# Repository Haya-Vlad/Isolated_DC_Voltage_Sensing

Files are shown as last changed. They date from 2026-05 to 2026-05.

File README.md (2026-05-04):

# Isolated DC Voltage Sensing

A fully isolated DC bus voltage sensing circuit designed for power electronics applications, capable of sensing **0–300 V DC** and scaling the signal to a **0–3.3 V ADC range** using the AMC1200 isolation amplifier.

## Table of Contents

- [Overview](#overview)
- [Features](#features)
- [Circuit Architecture](#circuit-architecture)
- [Signal Chain](#signal-chain)
- [Components](#components)
- [Repository Structure](#repository-structure)
- [Hardware Design](#hardware-design)
- [Power Supply](#power-supply)
- [Getting Started](#getting-started)
- [Bill of Materials](#bill-of-materials)
- [License](#license)

---

## Overview

This project implements a  isolated DC voltage sensing solution for high-voltage DC bus measurements (up to 300 V). The circuit uses the **AMC1200** precision isolation amplifier to safely measure high-voltage DC signals while maintaining full electrical isolation between the high-voltage side and the low-voltage (microcontroller/ADC) side.

The design is suitable for use in:
- Motor drives and inverters
- Battery management systems (BMS)
- Solar/PV converters
- DC-DC converters
- Any power electronics system requiring isolated voltage feedback

---

## Features

-  **Input range:** 0–300 V DC
-  **Output range:** 0–3.3 V (direct ADC-compatible)
-  **Full galvanic isolation** via AMC1200
-  **Anti-aliasing filter** at ADC input (150 Ω + 1 nF)
-  **RC pre-filter** for noise reduction before AMC1200
-  **Dual isolated power supply** using LD1117 and L7805 regulators
-  **Unipolar signal path** — no DC offset reference required
-  **MCP6002 op-amp** for output signal conditioning
-  **Designed in Eagle CAD**, Gerber files included
-  **Practically implemented and tested**

---

## Circuit Architecture

```
DC Bus (0–300V)
      │
      ▼
┌─────────────────────┐
│  Resistor Divider   │  620kΩ × 3 on each rail
│  (High-side input   │  which scales to ±250mV differential
│   attenuation)      │
└────────┬────────────┘
         │ Differential ±250mV
         ▼
┌─────────────────────┐
│      AMC1200        │  Isolation amplifier
│  (Isolation Stage)  │  Gain = 8 (±250mV in → ±2V out)
│                     │  Galvanic isolation barrier
└────────┬────────────┘
         │
         ▼
┌─────────────────────┐
│   RC Filter Stage   │  Initial noise suppression
│  (12Ω + 330pF)      │
└────────┬────────────┘
         │
         ▼
┌─────────────────────┐
│      MCP6002        │  Signal conditioning op-amp
│  (Output Scaling)   │  Scales to 0–3.3V ADC range
│                     │  10kΩ feedback network
└────────┬────────────┘
         │
         ▼
┌─────────────────────┐
│  Anti-Aliasing      │  150Ω + 1nF
│  Filter             │  High-frequency noise rejection
└────────┬────────────┘
         │
         ▼
    OUTPUT_TO_ADC (0–3.3V)
```

---

## Signal Chain

1. **Input Attenuation:** The DC bus voltage (0–300 V) is divided by a high-value resistor network  to produce a small differential voltage within the AMC1200's ±250 mV input range.

2. **Isolation (AMC1200):** The AMC1200 isolation amplifier provides galvanic isolation with a fixed gain of 8. The ±250 mV differential input is amplified and transferred across the isolation barrier.

3. **RC Pre-filter:** A 12 Ω + 330 pF RC filter stage provides initial high-frequency noise attenuation immediately after the AMC1200 output.

4. **Signal Conditioning (MCP6002):** The MCP6002 op-amp is configured as a scaling amplifier with a 10 kΩ feedback network. Since the DC bus signal is inherently unipolar, no DC offset reference is required so the signal maps directly into the 0–3.3 V ADC range.

5. **Anti-Aliasing Filter:** A 150 Ω + 1 nF RC filter at the ADC input provides additional high-frequency noise suppression and prevents aliasing during ADC sampling.

---

## Components

| Reference | Component | Value/Part | Description |
|---|---|---|---|
| U32 | AMC1200 | AMC1200 | Precision isolation amplifier |
| U37 | MCP6002 | MCP6002 | Dual rail-to-rail op-amp |
| CR2 | LD1117 | LD1117 | LDO voltage regulator (isolated side) |
| CR5 | L7805 | L7805 | 5V linear regulator |
| D3, D4 | HSMG-C170 | HSMG-C170 | Green & Red status LED |
| R177–R179, R183–R187 | Resistor | 620 kΩ | Input voltage divider |
| R170, R172–R173 | Resistor | 12 Ω | RC filter resistors |
| R174–R175 | Resistor | 10 kΩ | Op-amp feedback network |
| R259 | Resistor | 150 Ω | Anti-aliasing filter |
| R257, R258 | Resistor | 510 Ω | LED current limiting |
| C122, C125 | Capacitor | 330 pF | RC filter capacitors |
| C126, C127 | Capacitor | 0.1 µF | Decoupling capacitors |
| C153, C155 | Capacitor | 470 µF | Bulk filtering |
| C157, C161–C162 | Capacitor | 100 nF | Supply decoupling |
| C158 | Capacitor | 1 nF | Anti-aliasing filter capacitor |
| L3 | Ferrite Beads | 32mohms | Power supply filter |

---

## Repository Structure

```
isolated-dc-voltage-sensing/
│
├── README.md                  ← You are here
├── LICENSE
├── CHANGELOG.md
│
├── hardware/
│   ├── eagle/
│   │   ├── schematic/         ← .sch Eagle schematic files
│   │   ├── board/             ← .brd Eagle board layout files
│   │   └── libraries/         ← Custom Eagle component libraries (.lbr)
│   ├── gerber/                ← Fabrication-ready Gerber files
│   │   ├── *.GTL              (Top copper)
│   │   ├── *.GBL              (Bottom copper)
│   │   ├── *.GTS              (Top soldermask)
│   │   ├── *.GBS              (Bottom soldermask)
│   │   ├── *.GTO              (Top silkscreen)
│   │   ├── *.DRL              (Drill file)
│   │   └── gerber_readme.md
│   │
│── docs/
    ├── design_notes.md        ← Design decisions and calculations
    ├── signal_chain.md        ← Detailed signal chain analysis
    └── datasheets/            ← Key component datasheets (PDFs)
        ├── AMC1200.pdf
        ├── MCP6002.pdf
        ├── LD1117.pdf
        └── L7805.pdf
```

---

## Hardware Design

The design was created in **Autodesk Eagle CAD**. All source files are located under `hardware/eagle/`.

- **Schematic:** `hardware/eagle/schematic/`
- **Board layout:** `hardware/eagle/board/`
- **Gerber files** (ready for PCB fabrication): `hardware/gerber/`

### Power Supply Architecture

The circuit uses a **dual isolated power supply**:
- **VCC_A / GND_A** — High-voltage (DC bus) side supply, regulated via LD1117
- **VCC_B / GND_B** — Low-voltage (MCU/ADC) side supply, regulated via L7805
- **VCC_12V_A+ / VCC_12V_B+** — 12V rails feeding each regulator

The dual-supply architecture ensures that the isolation barrier of the AMC1200 is maintained across both the signal path and the power supply.

---

## Getting Started

### PCB Fabrication
1. Download the Gerber files from `hardware/gerber/`
2. Upload to your preferred PCB manufacturer (JLCPCB, PCBWay, OSHPark, etc.)
3. Recommended specs: 2-layer, 1.6 mm FR4, HASL or ENIG finish

### Assembly
1. Refer to `hardware/bom/bom.csv` for component sourcing
2. Follow the schematic in `hardware/eagle/schematic/`
3. Pay attention to orientation of AMC1200 and polarized capacitors

### Testing
1. Apply a known DC voltage of 12V to DC_A / DC_B inputs
2. Measure OUTPUT_TO_ADC with a multimeter or oscilloscope
3. Verify scaling linearity against expected values 

---

## Bill of Materials

See [`hardware/BOM`](hardware/BOM/BOM.pdf) for the complete BOM.

---

## License

This project is released under the [MIT License](LICENSE).

---

## Author

**Aditya Gohil**  
Power Electronics Design  
*Designed and practically implemented — May 2026*

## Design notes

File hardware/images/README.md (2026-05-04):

# Images

Add the following images here:

- `schematic.png` — Exported schematic from Eagle (File → Export → Image)
- `pcb_top.png` — PCB top layer render
- `pcb_bottom.png` — PCB bottom layer render
- `assembled_board.jpg` — Photo of the practically implemented board

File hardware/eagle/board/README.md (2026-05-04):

# Eagle Board Files

Place your Eagle `.brd` board layout file(s) here.

- `pe_project.brd` — PCB layout

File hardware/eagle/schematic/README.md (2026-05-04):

# Eagle Schematic Files

Place your Eagle `.sch` schematic file(s) here.

- `pe_project.sch` — Main schematic

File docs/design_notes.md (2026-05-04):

# Design Notes — Isolated DC Voltage Sensing

**Author:** Aditya Gohil  
**Date:** May 2026  
**Tool:** Autodesk Eagle CAD

---

## 1. Design Goals

- Measure DC bus voltages in the range **0–300 V**
- Provide **galvanic isolation** between high-voltage and low-voltage domains
- Output a signal in the **0–3.3 V range** suitable for direct ADC sampling
- Minimize noise at the ADC input
- Keep the design compact and cost-effective

---

## 2. Component Selection

### AMC1200 — Isolation Amplifier
The AMC1200 was chosen for its:
- Fixed gain of 8 with ±250 mV differential input range
- High isolation voltage (up to 4250 V peak)
- Low offset voltage and excellent linearity
- SPI-free, analog-in/analog-out interface — no firmware dependency

### MCP6002 — Signal Conditioning Op-Amp
The MCP6002 was selected for its:
- Rail-to-rail input/output capability
- Single-supply operation (3.3V or 5V compatible)
- Low cost, widely available dual op-amp package
- Sufficient bandwidth for DC sensing applications

### LD1117 / L7805 — Voltage Regulators
- **LD1117 (ADJ):** Used on the isolated (high-voltage) side to supply the AMC1200 VDD
- **L7805:** Used on the low-voltage side to supply the MCP6002 and output circuitry

---

## 3. Input Attenuation Network

### Resistor Divider Calculation

The DC bus voltage (0–300 V) must be scaled to the AMC1200's ±250 mV differential input range.

Each leg of the differential input uses **3 × 620 kΩ resistors in series = 1.86 MΩ**.

A **2.2 kΩ** differential sense resistor is placed between the two legs.

Differential voltage across sense resistor:
```
V_diff = V_bus × (R_sense / (2 × R_series + R_sense))
V_diff = 300 × (2200 / (2 × 1,860,000 + 2200))
V_diff ≈ 300 × (2200 / 3,722,200)
V_diff ≈ 300 × 0.000591
V_diff ≈ 177 mV  (well within ±250 mV limit)
```

This gives comfortable headroom within the AMC1200 input range.

---

## 4. AMC1200 Output Scaling

The AMC1200 has a fixed gain of **8**.

Output voltage from AMC1200 for max input (±250 mV):
```
V_out_AMC = ±250 mV × 8 = ±2 V
```

Since the DC bus signal is unipolar (0–300 V), the output of the AMC1200 is also unipolar (0 to ~1.4 V at 300 V input given the actual divider ratio).

---

## 5. MCP6002 Gain Stage

The MCP6002 is configured as a non-inverting amplifier to scale the AMC1200 output to the 0–3.3 V ADC range.

Gain is set by the 10 kΩ feedback resistors.

Since the signal is unipolar, no virtual ground or DC offset reference is needed — the signal naturally maps into the positive ADC range.

---

## 6. Filtering Strategy

### Stage 1 — RC Pre-filter (after AMC1200 output)
- **R = 12 Ω, C = 330 pF**
- Cut-off frequency: `f_c = 1 / (2π × 12 × 330×10⁻¹²) ≈ 40 MHz`
- Provides initial HF noise damping

### Stage 2 — Anti-Aliasing Filter (at ADC input)
- **R = 150 Ω, C = 1 nF**
- Cut-off frequency: `f_c = 1 / (2π × 150 × 1×10⁻⁹) ≈ 1.06 MHz`
- Prevents aliasing during ADC sampling
- This is the dominant low-pass filter in the signal chain

---

## 7. Isolation Barrier Considerations

The AMC1200 provides isolation between:
- **VCC_A / GND_A** domain (connected to DC bus side)
- **VCC_B / GND_B** domain (connected to MCU/ADC side)

Both power domains are independently regulated. The 12V input rails (VCC_12V_A+ and VCC_12V_B+) must themselves come from an isolated DC-DC converter upstream, or from separate transformer-derived supplies, to maintain the full isolation chain.

---

## 8. Known Limitations

- The resistor divider introduces some power dissipation at high bus voltages (~24 mW at 300 V) — acceptable for most applications
- The AMC1200 output is referenced to the isolated GND_A; level shifting is handled by the dual-supply scheme
- Accuracy is limited by resistor tolerance of the divider network — use 1% or 0.1% resistors for best precision

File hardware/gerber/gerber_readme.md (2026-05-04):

# Gerber Files

This folder contains the PCB fabrication files exported from Eagle CAD.

## File Naming Convention (Eagle default)

| File Extension | Layer Description |
|---|---|
| `.GTL` | Top copper layer |
| `.GBL` | Bottom copper layer |
| `.GTS` | Top soldermask |
| `.GBS` | Bottom soldermask |
| `.GTO` | Top silkscreen |
| `.GBO` | Bottom silkscreen |
| `.GKO` | Board outline (keepout) |
| `.DRL` | Drill file (Excellon) |
| `.TXT` | NC drill file |

## Recommended PCB Specs

| Parameter | Value |
|---|---|
| Layers | 2 |
| Board thickness | 1.6 mm |
| Copper weight | 1 oz (35 µm) |
| Surface finish | HASL or ENIG |
| Min trace width | 6 mil |
| Min drill size | 0.3 mm |
| Solder mask | Green (both sides)|
| Silkscreen | White (top side)  |

## Ordering

Upload the contents of this folder as a `.zip` to your PCB manufacturer.  
Tested with: JLCPCB, PCBWay.

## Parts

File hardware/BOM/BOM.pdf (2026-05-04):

Sr. No | Comment | Designator | Quantity | Manufacturer URL | Supplier | Price of each component (INR) | Price of total needed component (INR)
1 | 2.2K 1206 | R177 | 2 | https://robu.in/product/frc1206f (https://robu.in/product/frc1206f2201ts-fojan-250mw-thick-film-resistors-200v-%c2%b1100ppm-%e2%84%83-%c2%b11-2-2k%cf%89-1206-chip-resistor-surface-mount-rohs) | ROBU | 0.18 | 0.36
2 | 12R 1206 | R171, R173 | 4 | https://robu.in/product/rc1206fr- (https://robu.in/product/rc1206fr-0712rl-yageo-smd-chip-resistor-12-ohm-%c2%b1-1-250-mw-1206-3216-metric-thick-film-general-purpose) | ROBU | 0.24 | 0.96
3 | 10K 1206 | R174, R175, R176 | 3 | https://robu.in/product/cr1206j1 (https://robu.in/product/cr1206j10k0p05z-ever-ohms-tech-250mw-thick-film-resistor-%c2%b1100ppm-%e2%84%83-%c2%b15-10k%cf%89-1206-chip-resistor-surface-mount-rohs) | ROBU | 0.75 | 2.25
4 | 150R 1206 | R259 | 1 | https://robu.in/product/rc1206fr- (https://robu.in/product/rc1206fr-07150rl-yageo-250mw-thick-film-resistors-200v-%c2%b1100ppm-%e2%84%83-%c2%b11-150%cf%89-1206-chip-resistor-surface-mount-rohs) | ROBU | 0.43 | 0.43
5 | 510R 1206 | R255, R257 | 2 | | ROBU | 0.24 | 0.48
6 | 0.1uf 1206 | C127, C157, C161, C162, C158 | 7 | https://robu. | ROBU | 3 | 21

https://robu.
in/product/rc1206fr- (https://robu.in/product/rc1206fr-07510rl-yageo-res-thick-film-1206-510-ohm-1-0-25w1-4w-%c2%b1100ppm-c-pad-smd-t-r)

in/product/ac1206k (https://robu.in/product/ac1206kkx7r0bb104-yageo-cap-ceramic-0-1uf-100v-x7r-10-pad-smd-1206-125c-automotive-aec-q200-t-r)
7 | SMD LED 0603 | D3, D4
2

https://robu.
in/product/everlight (https://robu.in/product/everlight-1-5mm-blue-smd-led-pack-of-10)
ROBU | 1.41 | 2.82
8 | AMC1200 | U32 | 1 | https://robu.in/product/amc131 (https://robu.in/product/amc1311bqdwvrq1-texas-instruments-soic-8-300mil-special-purpose-amplifiers-rohs) | ROBU | 252 | 252
10 | MCP6002 | U37 | 1 | https://robu. | ROBU | 41 | 41
in/product/mcp600 (https://robu.in/product/mcp6002-i-sn-microchip-tech-2-1pa-600v-ms-4-5mv-soic-8-operational-amplifier-rohs)
11 | L7805 DIP-3 | CR5 | 1 | https://robu.in/product/1-month- (https://robu.in/product/1-month-warranty-441) | ROBU | 30 | 30
12 | LD1117 | CR2 (Regulator) | 1 | | ROBU | 19 | 19
13 | 470uf DIP | C183 | 1 | https://robu.in/product/uvr1c47 (https://robu.in/product/uvr1c471mpd1td-nichicon-470uf-16v-%c2%b120-440ma120hz-plugin-aluminum-electrolytic-capacitors-leaded-rohs) | ROBU | 13 | 13
14 | 100uf 1206 | C155 | 1 | https://robu.in/product/grm31cr (https://robu.in/product/grm31cr61a107mea8l-murata-electronics-10v-100uf-x5r-%c2%b120-1206-multilayer-ceramic-capacitors-mlcc-smd-smt-rohs) | ROBU | 20 | 20
15 | 330pf 1206 | C122, C126 | 2 | https://robu. | ROBU | 2.08 | 4.16

https://robu.
in/product/1-month- (https://robu.in/product/1-month-warranty-1381)

in/product/330pf- (https://robu.in/product/330pf-1206-surface-mount-multilayer-ceramic-capacitor-pack-of-30)
16 | 2-Pin Terminal | X1-2, B1-2 | 3 | | ROBU | 11 | 33
17 | 620K Resistor | R178, R179, R180, R185, R186, R187 | 6 | https://robu.in/product/wr12x62 (https://robu.in/product/wr12x624jtl-walsin-250mw-thick-film-resistors-200v-%c2%b1100ppm-%e2%84%83-%c2%b15-620k%cf%89-1206-chip-resistor-surface-mount-rohs) | ROBU | 0.15 | 0.9
Total | | | 32 | | | 394.48 | 441.36

https://robu.
in/product/2-pin-7- (https://robu.in/product/2-pin-7-5-mm-pcb-terminal-block)

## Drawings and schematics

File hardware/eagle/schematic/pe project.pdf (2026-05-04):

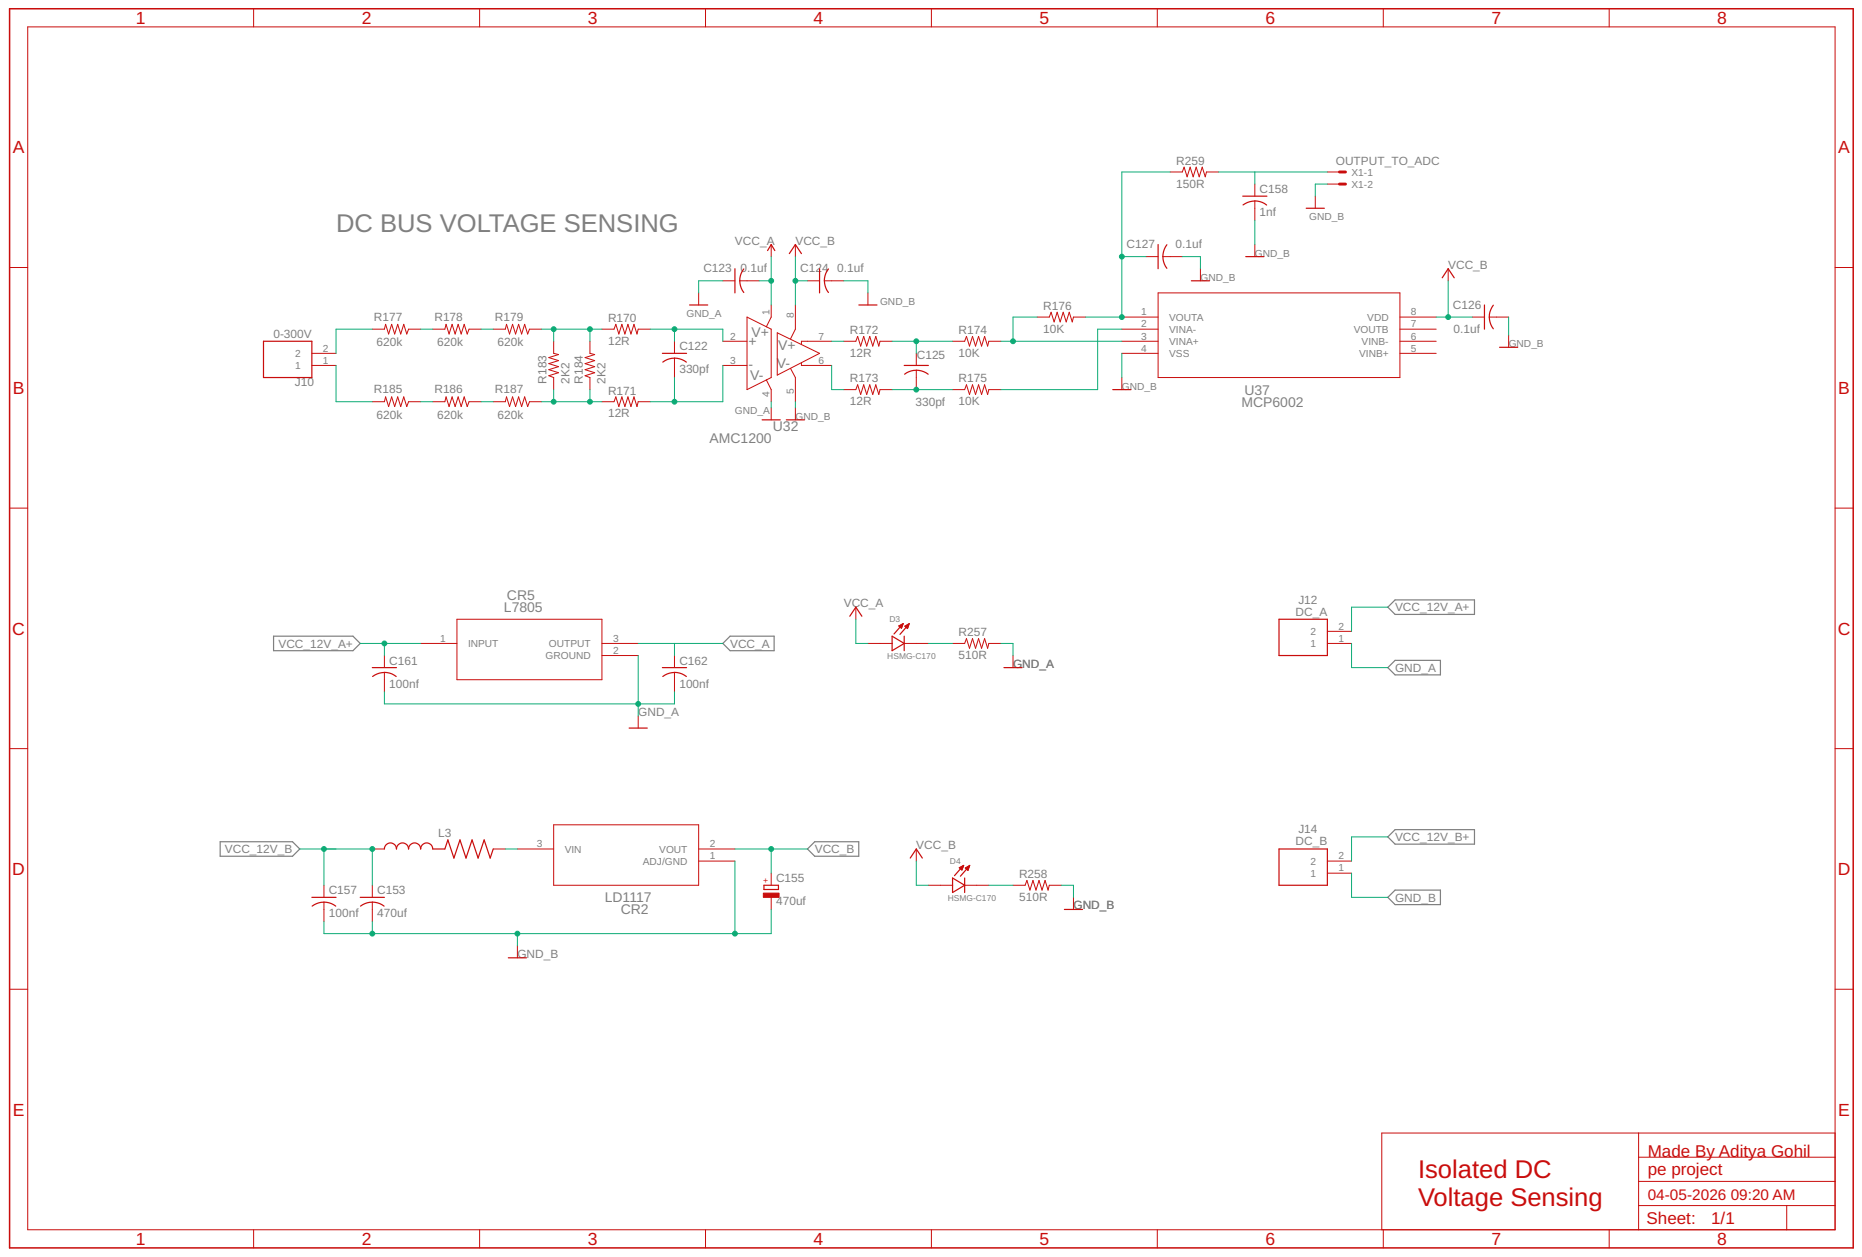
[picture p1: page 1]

DC BUS VOLTAGE SENSING

Made By Aditya Gohil
pe project

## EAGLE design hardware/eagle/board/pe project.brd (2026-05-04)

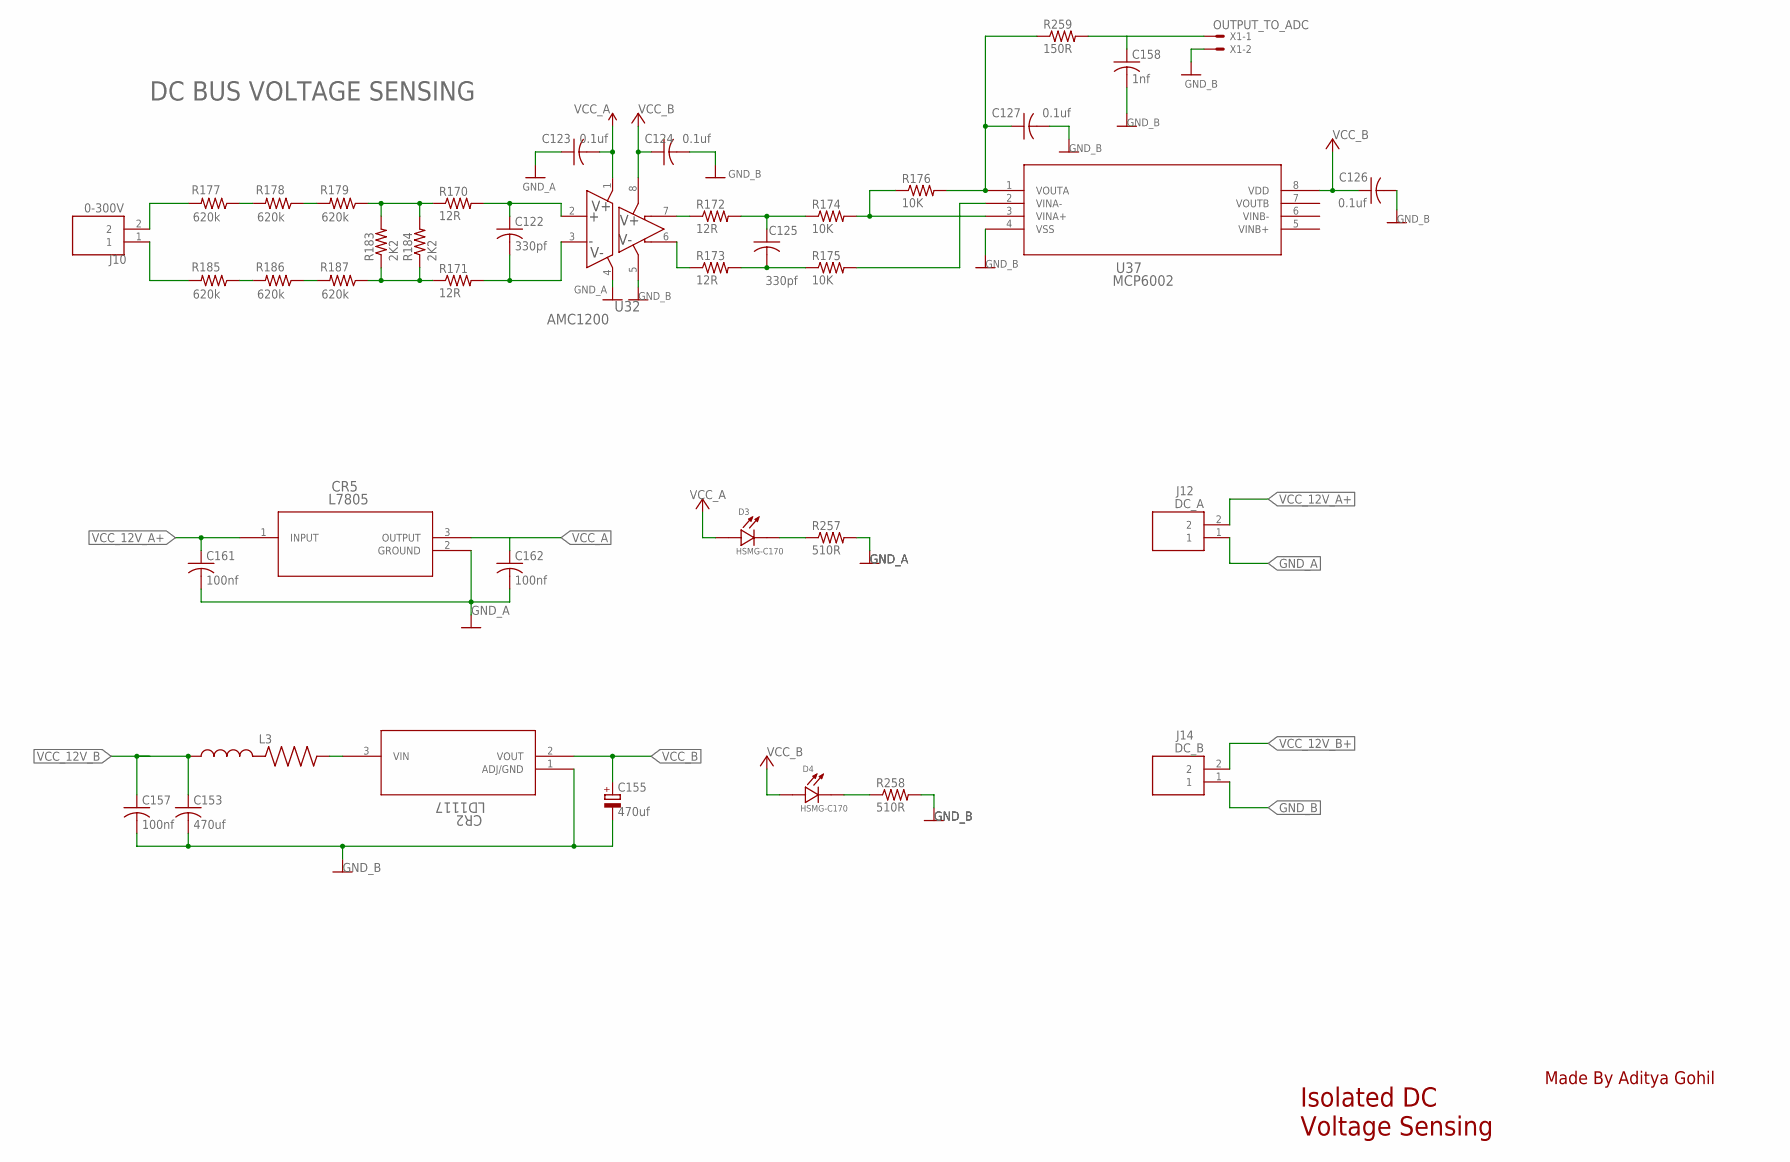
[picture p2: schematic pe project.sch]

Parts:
C122, C125: 330pf; C1206
C123, C124, C126, C127: 0.1uf; C1206
C153: 470uf; C1206
C155: 470uf; E3,5-8
C157, C161, C162: 100nf; C1206
C158: 1nf; C1206
CR2: LD1117; SOT-223_STM
CR5: L7805; TO-220_STM
D3, D4: HSMG-C170; LED_HSMS-C170
J10: 0-300V; TE_5-1437648-7
J12: DC_A; TE_5-1437648-7
J14: DC_B; TE_5-1437648-7
L3: 32ohm; BEADC3225X220N
R170, R171, R172, R173: 12R; R1206
R174, R175, R176: 10K; R1206
R177, R178, R179, R185, R186, R187: 620k; R2512
R183, R184: 2K2; R1206
R257, R258: 510R; R1206
R259: 150R; R1206
U32: AMC1200; DUB0008A_N
U37: MCP6002; SOIC8-N_MC_MCH
X1: OUTPUT_TO_ADC; 22-23-2021

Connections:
AC_V_B_OUT: C127.1, R176.2, R259.1, U37.1 (VOUTA)
GND_A: C123.1, C161.2, C162.2, CR5.2 (GROUND), J12.1, R257.2, U32.4 (GND1)
GND_B: C124.2, C126.2, C127.2, C153.2, C155.-, C157.2, C158.2, CR2.1 (ADJ/GND), J14.1, R258.2, U32.5 (GND2), U37.4 (VSS), X1.2
unnamed: R170.1, R179.1, R183.2, R184.2
unnamed: R171.1, R183.1, R184.1, R187.1
unnamed: C122.1, R170.2, U32.2 (VINP)
unnamed: R172.1, U32.7 (VOUTP)
unnamed: R173.1, U32.6 (VOUTN)
unnamed: C125.2, R173.2, R175.1
unnamed: C125.1, R172.2, R174.1
unnamed: R174.2, R176.1, U37.3 (VINA+)
unnamed: R177.1, R178.2
unnamed: R178.1, R179.2
unnamed: R175.2, U37.2 (VINA-)
unnamed: R185.1, R186.2
unnamed: R186.1, R187.2
unnamed: J10.2, R177.2
unnamed: J10.1, R185.2
unnamed: C122.2, R171.2, U32.3 (VINN)
unnamed: CR2.3 (VIN), L3.2
unnamed: D3.C, R257.1
unnamed: D4.C, R258.1
OUTPUT_TO_ADC: C158.1, R259.2, X1.1
VCC_12V_A+: C161.1, CR5.1 (INPUT), J12.2
VCC_12V_B: C153.1, C157.1, L3.1
VCC_12V_B+: J14.2
VCC_A: C123.2, C162.1, CR5.3 (OUTPUT), D3.A, U32.1 (VDD1)
VCC_B: C124.1, C126.1, C155.+, CR2.2 (VOUT), D4.A, U32.8 (VDD2), U37.8 (VDD)

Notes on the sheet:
DC BUS VOLTAGE SENSING
Isolated DC Voltage Sensing
Made By Aditya Gohil

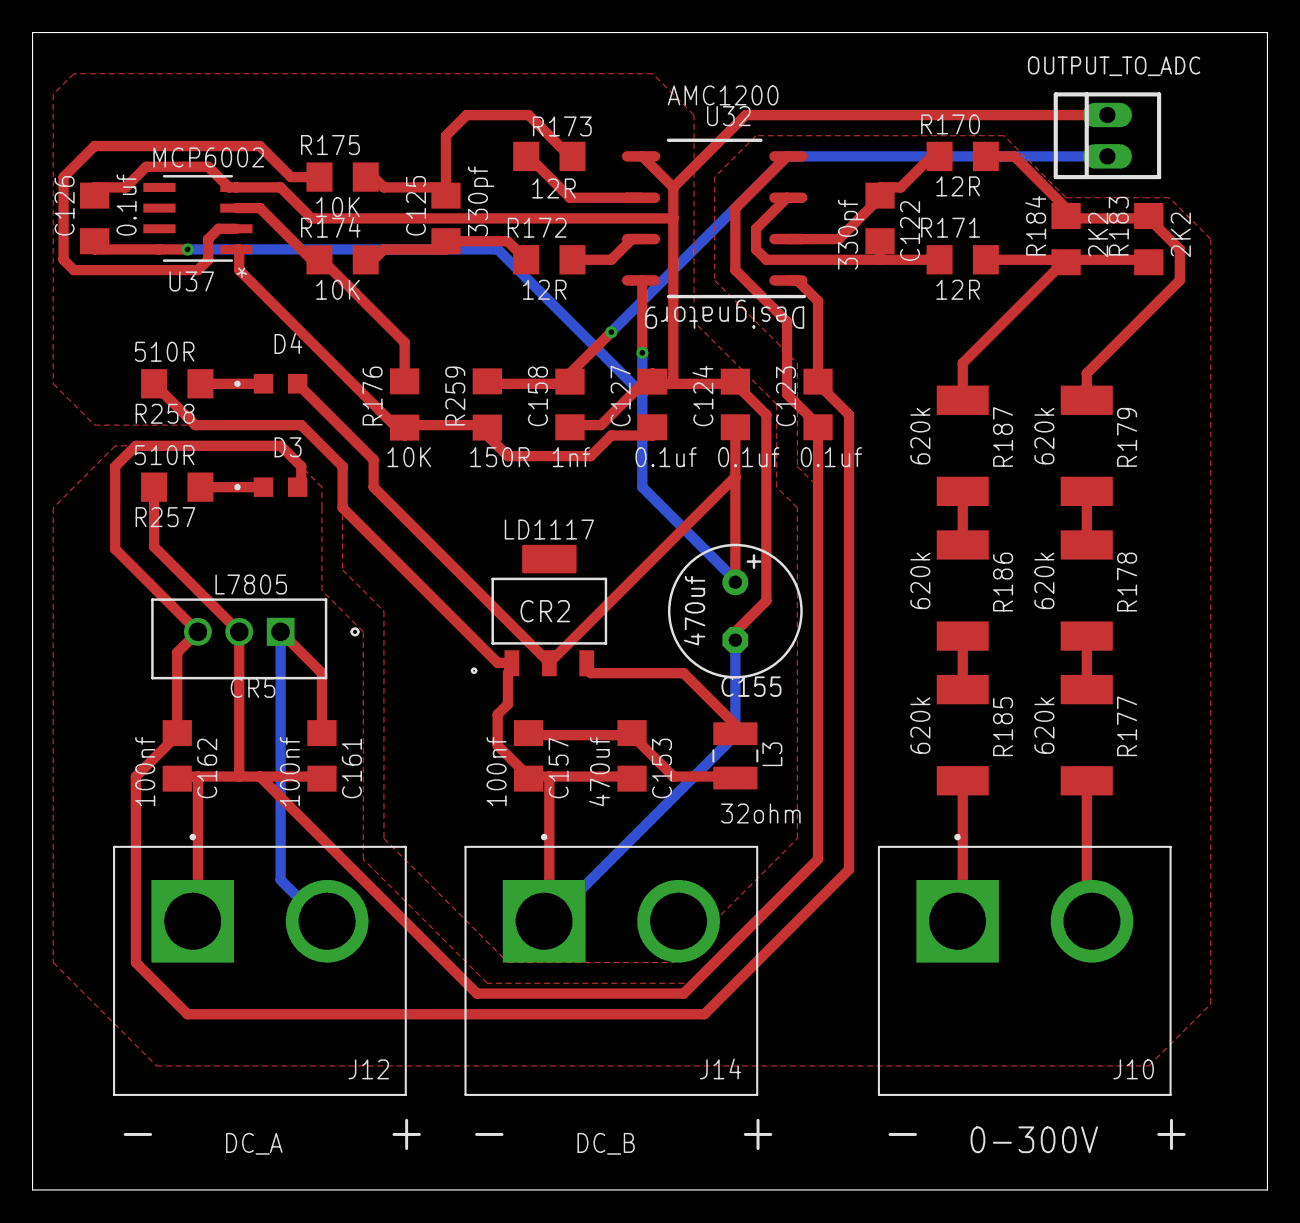
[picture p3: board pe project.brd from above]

Board: 2 copper layers, 75.9 x 71.1 mm, 41 parts (0 on the bottom side), 27 nets.

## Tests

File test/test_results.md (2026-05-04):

# Test Results — Isolated DC Voltage Sensing

**Tester:** Aditya Gohil  
**Date:** May 2026  
**Board Version:** v1.0

---

## Test Equipment Used

| Equipment | Model | Notes |
|---|---|---|
| DC Power Supply | — | Variable 0–300V |
| Multimeter | — | For OUTPUT_TO_ADC measurement |
| Oscilloscope | — | Noise / ripple observation |
| Logic Analyzer / MCU | — | ADC reading verification |

---

## Linearity Test — OUTPUT_TO_ADC vs Input Voltage

| DC Bus Input (V) | Expected ADC Output (V) | Measured ADC Output (V) | Error (%) |
|---|---|---|---|
| 0 | 0.000 | | |
| 30 | 0.330 | | |
| 60 | 0.660 | | |
| 100 | 1.100 | | |
| 150 | 1.650 | | |
| 200 | 2.200 | | |
| 250 | 2.750 | | |
| 300 | 3.300 | | |

*Fill in measured values during hardware testing.*

---

## Isolation Verification

- [ ] Confirm no DC continuity between GND_A and GND_B
- [ ] Confirm no DC continuity between DC bus input rails and OUTPUT_TO_ADC
- [ ] Hipot test (if applicable): ______ V applied for ______ seconds — Pass / Fail

---

## Noise / Ripple Measurement

| Condition | Frequency | Peak-to-Peak Noise (mV) | Notes |
|---|---|---|---|
| DC bus = 100V, no load | — | | |
| DC bus = 100V, switching load | — | | |

---

## Power Supply Rails

| Rail | Expected (V) | Measured (V) | Pass/Fail |
|---|---|---|---|
| VCC_12V_A+ (input) | 12.0 | | |
| VCC_A (LD1117 output) | | | |
| VCC_12V_B+ (input) | 12.0 | | |
| VCC_B (L7805 output) | 5.0 | | |

---

## Notes

*Add any observations, anomalies, or rework performed during testing here.*

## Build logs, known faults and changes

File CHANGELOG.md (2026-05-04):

# Changelog

All notable changes to this project will be documented here.

---

## [v1.0] — May 2026

### Added
- Initial release
- Eagle CAD schematic and board layout for isolated DC voltage sensing
- AMC1200-based galvanic isolation with 0–300V input range
- MCP6002 output signal conditioning stage
- Dual isolated power supply (LD1117 + L7805)
- Anti-aliasing RC filter at ADC input (150Ω + 1nF)
- Gerber files for PCB fabrication
- Bill of Materials (BOM)
- Practical hardware implementation and validation

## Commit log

2026-05-04 Uploading all the necessary changes
    [pe project.brd, pe project.sch, pe project.xlsx]
2026-05-04 Uploaded all the necessary docs
    [pe project.brd, pe project.sch, pe project.xlsx]
2026-05-04 Update BOM link in README.md
2026-05-04 Fix link to Bill of Materials PDF

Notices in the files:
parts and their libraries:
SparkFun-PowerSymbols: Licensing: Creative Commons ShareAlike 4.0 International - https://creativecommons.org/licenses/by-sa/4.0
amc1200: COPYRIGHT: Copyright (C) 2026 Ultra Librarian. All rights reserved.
